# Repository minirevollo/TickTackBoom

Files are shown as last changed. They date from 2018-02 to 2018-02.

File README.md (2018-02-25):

#TICK, TACK ...BOOM

Ein Ratespiel, ähnlich Stadt, Land, Fluss. Hier gibt es die [Spielanleitung](https://github.com/minirevollo/TickTackBoom/blob/master/IMG/TickTackBoom-Spielanleitung.pdf).	

 

Für den Arduino mit nur ein paar Bauteilen.

## Hardware ##
- Arduino (z. B. pro micro)
- OLED-Display 128 x 32 Pixel
- Buzzer passiv
- Button
- LED  (eignebaut)

Anschluß des Displays über I2C an die Pins SDA und SCL (beim Arduino UNO SDA = A4 und SCL = A5 für andere Arduinos bitte den PinOut-Plan beachten).
Der Button kommt auf Pin 7 und GND.
Der Buzzer zwischen Pin 11 und GND. 
Für die LED habe ich die eingbaute auf Pin 13 verwendet.

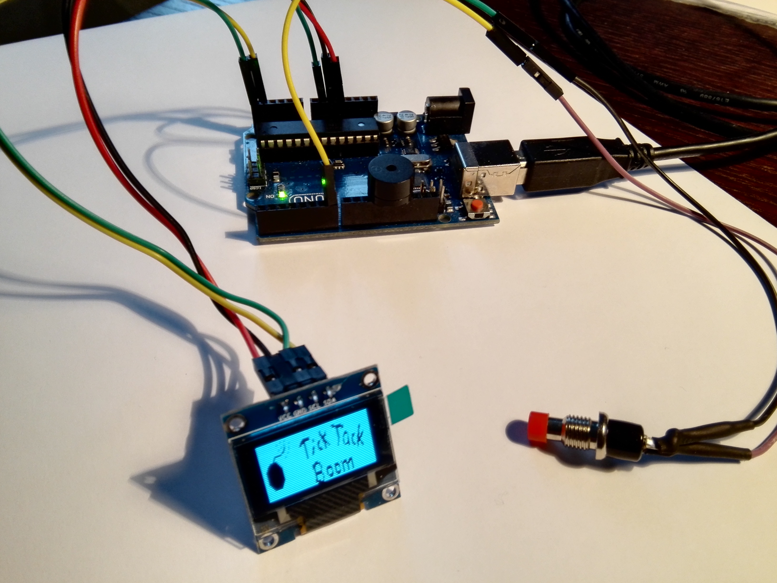
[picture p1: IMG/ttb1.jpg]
     

## Software ##
Arduino-Code über die Arduino-IDE aufspielen.Für absolute Anfänger hier der Link zu [ARDUINO](https://www.arduino.cc/).
Ihr benötigt noch zwei Bibliotheken von [Adafruit](http://www.adafruit.com/):
- Adafruit_GFX.h
- Adafruit_SSD1306.h
- und die entsprechenden .cpp-Dateien

Diese müssen unter dem Ordner 
... C:\Program Files (x86)\Arduino\libraries\Adafruit  abgelegt sein.

Man könnte auch andere OLED-Bibliotheken verwenden. Der Programmcode müsste dann entsprechend angepasst werden. 

Die Daten für den Startbildschirm "Tick Tack Boom" habe ich in meiner Adafruit_SSD1306.cpp Datei hinterlegt. 

Hier liegen normalerweise die Daten für das Adafruit-Logo. Diese Daten habe ich mit meinen Daten ersetzt. Um ein eigenes Logo zu gestalten, erzeuge mit einem Grafikprogramm (z.B. Paint) eine Gif-Datei 128 x 32 Pixel mit euerem gewünschten Motiv. Auf der Website http://www.majer.ch/lcd/adf_bitmap.php kann diese Datei dann in HEX-Daten umgewandelt werden. Die Daten kopieren und die Daten für das Adafruit-Logo damit überschreiben.

Der Code ist so ausgelegt, das für jeden Spielmodus 29 Werte hinterlegt sind. Wenn noch mehr Werte gewünscht sind, müssen die entsprechenden arrays t, b und g entsprechend erweitert werden.

## Gehäuse 

Es wurden zwei Gehäusetypen von mir konstruiert. Zum Einen das komplett 3D-gedruckte Gehäus. Bestehend aus einer Bodenplatte mit Wölbung. Gedacht für zwei zylinderförmige Powerbanks mit einem Durchmesser von ca. 22 mm. Zu befestigen mit zwei dicken Gummibändern. Und dem Oberteil. Innen benötigt man noch eine Stütze für das Display und die Buttonverlängerung. 

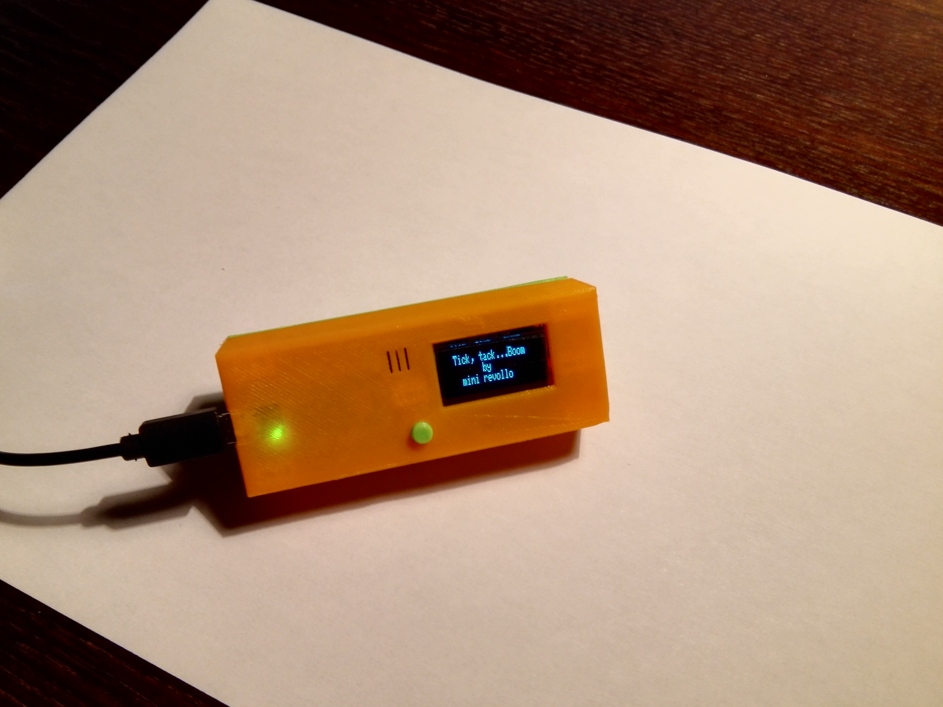
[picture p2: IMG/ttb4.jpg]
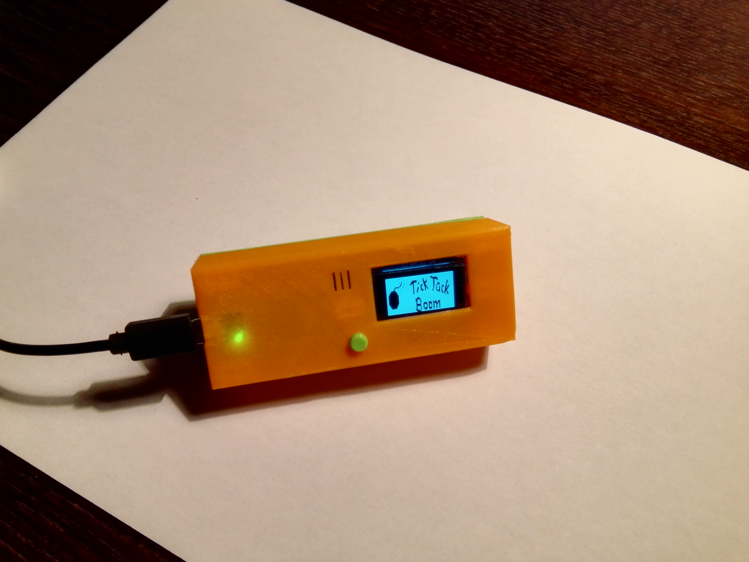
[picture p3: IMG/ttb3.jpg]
     

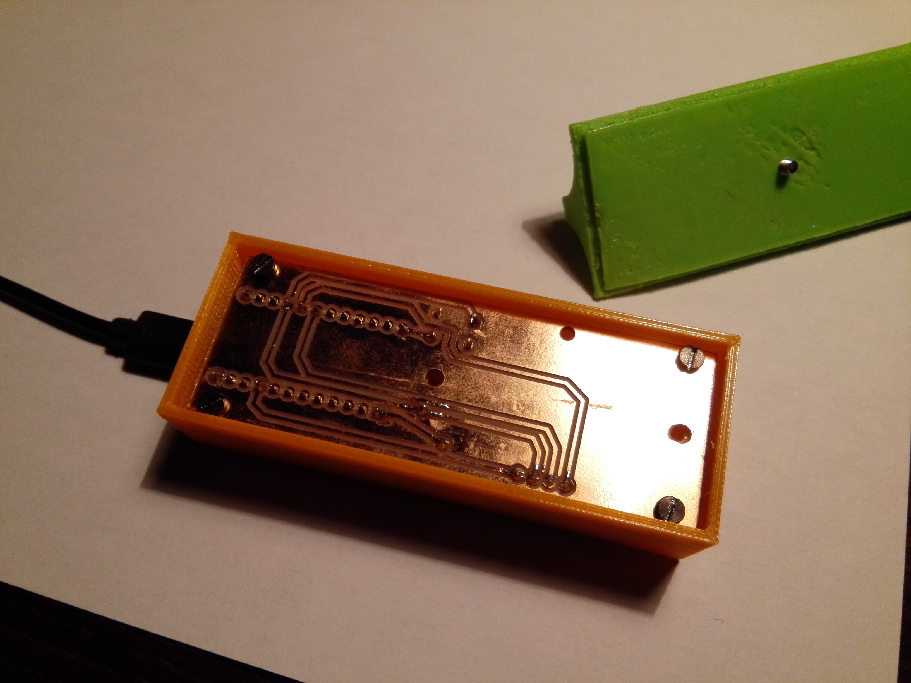
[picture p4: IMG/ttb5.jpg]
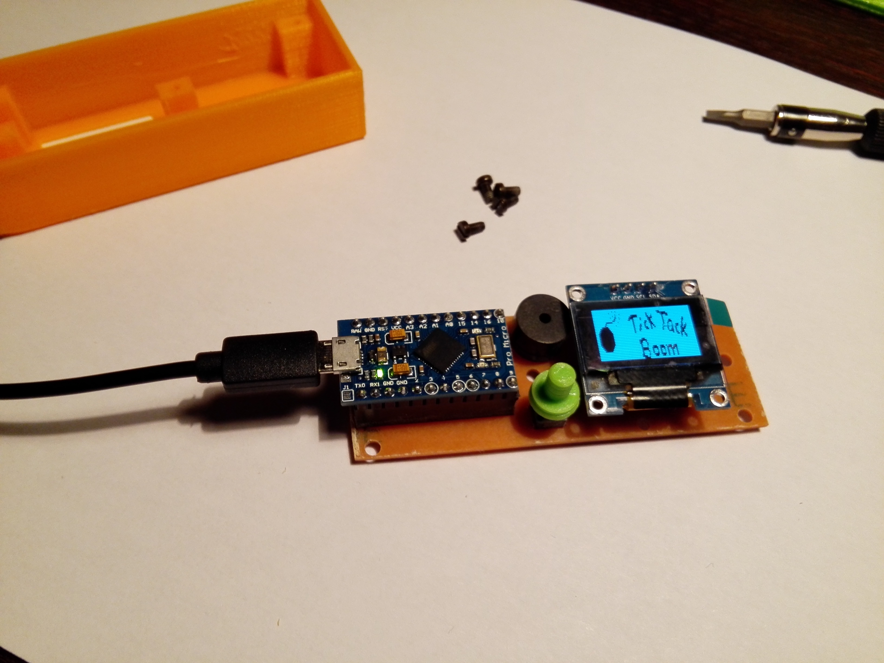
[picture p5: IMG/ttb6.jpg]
  

Für meine Freundin habe ich dann noch die Edelvariante mit Eichenholz und rotem Filament produziert. Der mittlere Teil, die Displaystütze und der Button wurde wieder 3D-gedruckt. Der Deckel und das Unterteil wurde mit einer Othermill gefräst. Hierfür wurde aus der aus Sketchup exportierten DXF-Datei mit [ESTLCAM](http://www.estlcam.de) eine .tap-Datei (g-code) 
erzeugt. 

An dieser Stelle nochmal vielen Dank an Christian, den Programmierer von ESTLCAM, der dem erfindergarden eine Lizenz zur Verfügung gestellt hat.

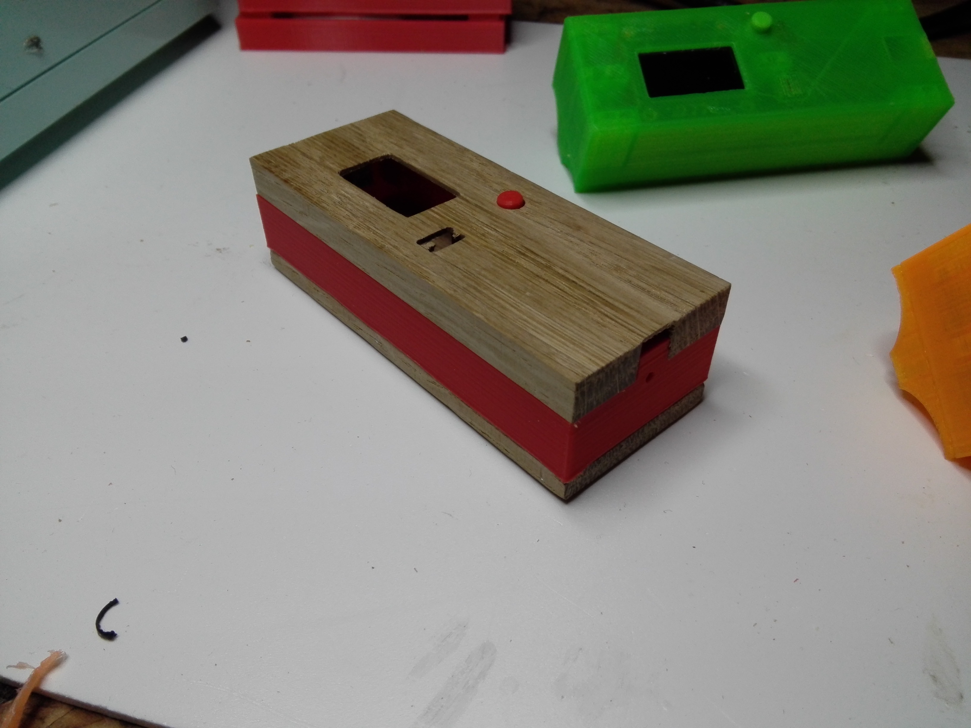
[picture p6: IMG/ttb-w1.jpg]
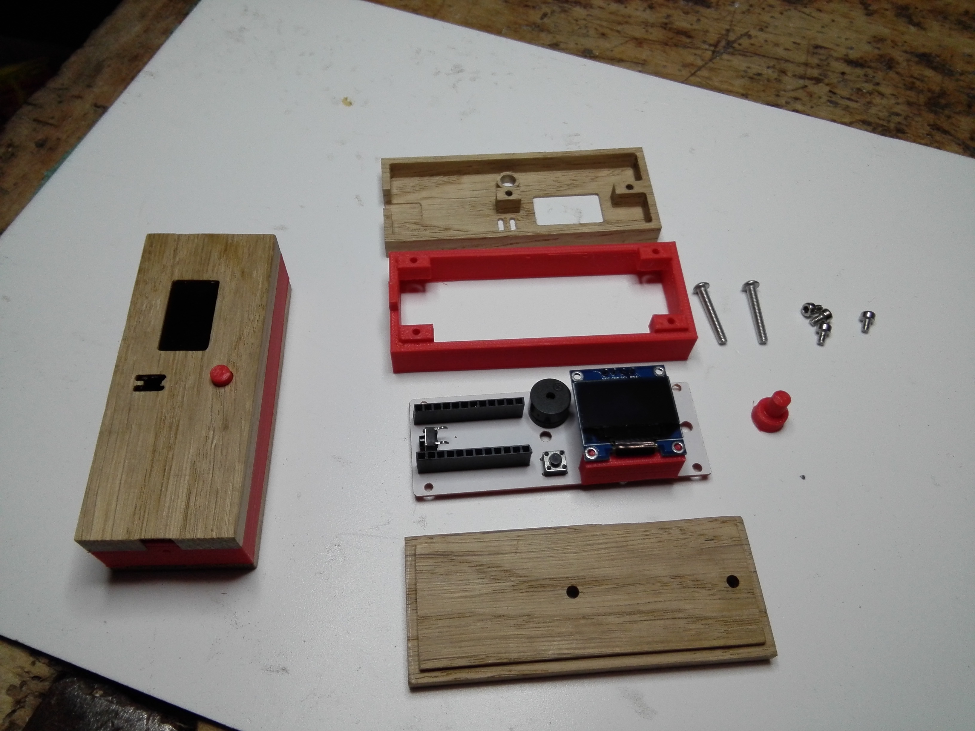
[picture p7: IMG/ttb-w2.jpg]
     

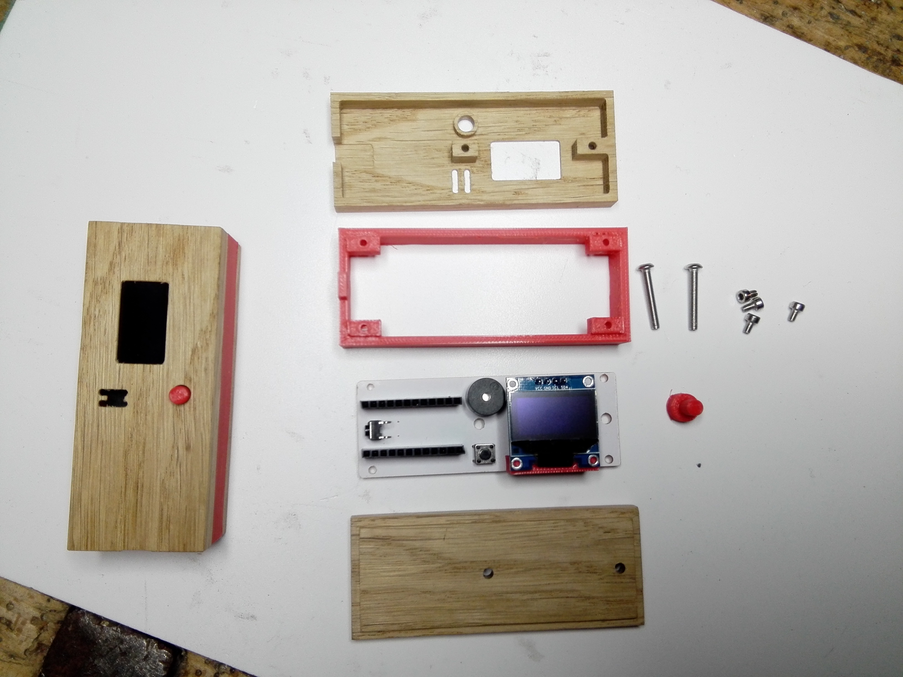
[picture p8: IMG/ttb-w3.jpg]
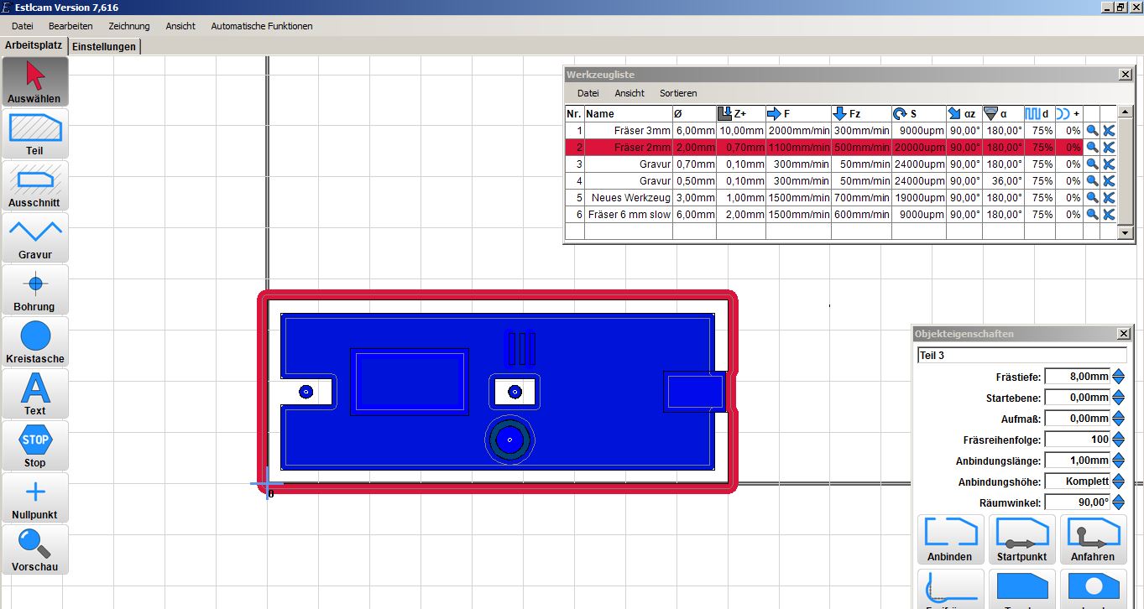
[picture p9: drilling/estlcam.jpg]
 

## Platine: ##

Die Platine wurde mit Fritzing gebaut. Die Form für das Board wurde auch aus der DXF-Datei von Sketchup übernommen und in Inkscape überarbeitet. Um die generierte SVG-Datei für Fritzing nutzbar zu machen muss man einer speziellen Anleitung folgen, die man bei Fritzing auch findet. Export aus Fritzing dann als Gerber-File. Gefräst wieder mit der Othermill.

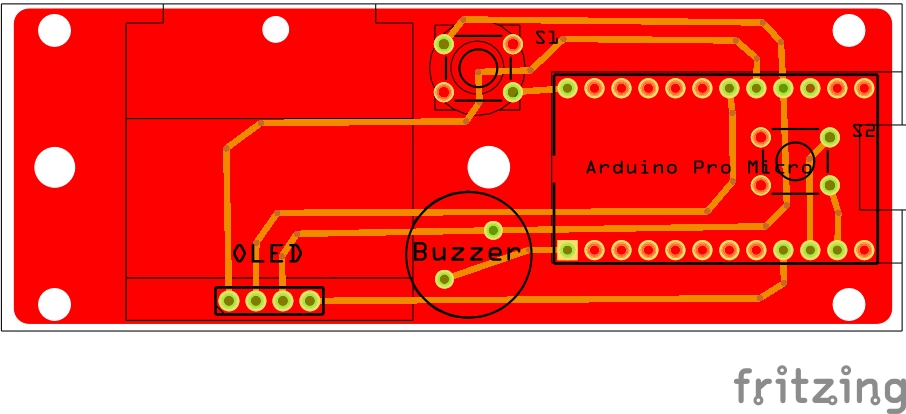
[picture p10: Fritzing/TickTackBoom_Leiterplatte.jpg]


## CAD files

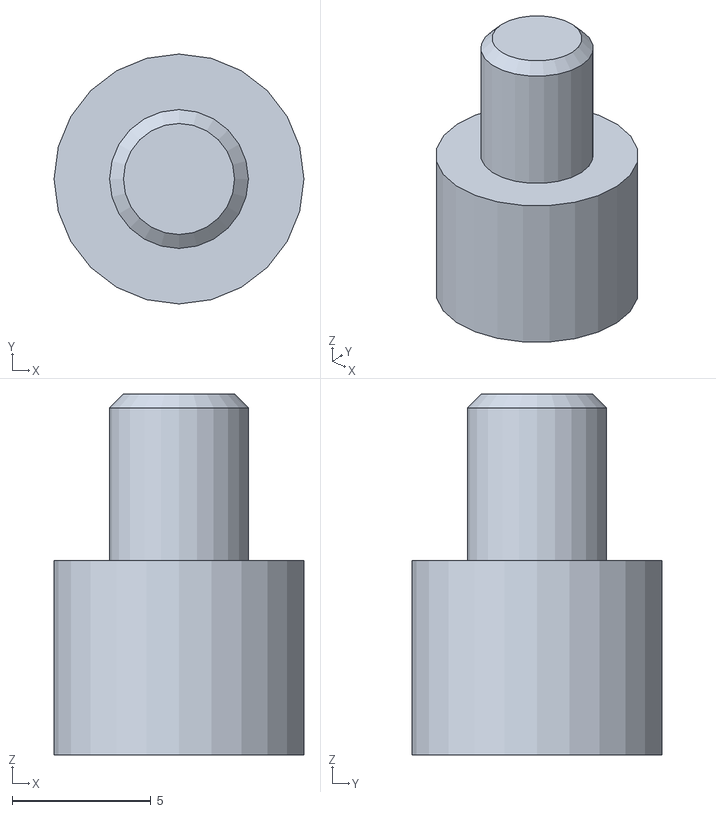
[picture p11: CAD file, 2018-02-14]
3D/ttb_taster_14.stl
9.00 x 9.00 x 13.0

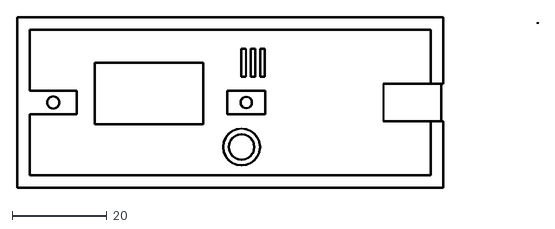
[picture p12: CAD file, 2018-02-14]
drilling/TickTackBoom_Holz.dxf
110.4 x 36.4

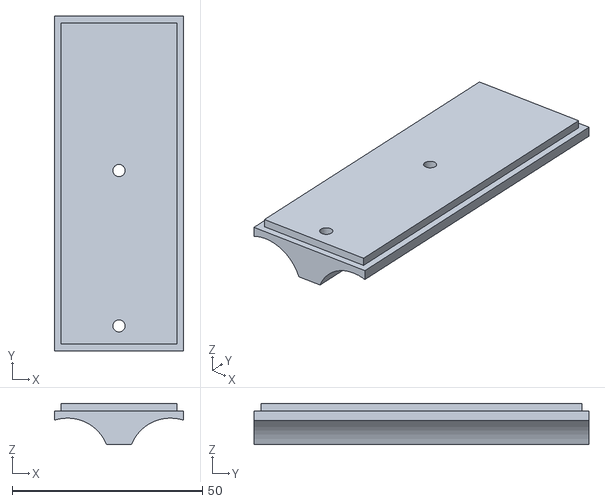
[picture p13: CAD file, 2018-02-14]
3D/ttb_unterteil.stl
34.0 x 88.0 x 10.9

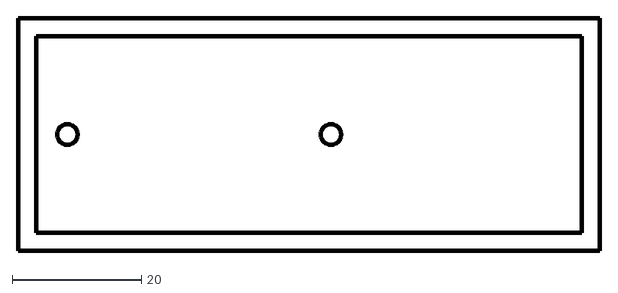
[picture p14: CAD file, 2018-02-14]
drilling/TickTackBoom_Holz_unten.dxf
90.6 x 36.6

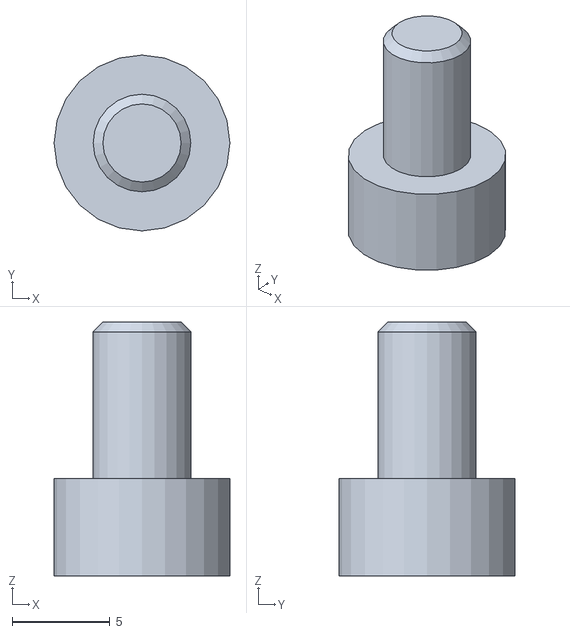
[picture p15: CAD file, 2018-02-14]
3D/ttb_taster_13.stl
9.00 x 9.00 x 13.0

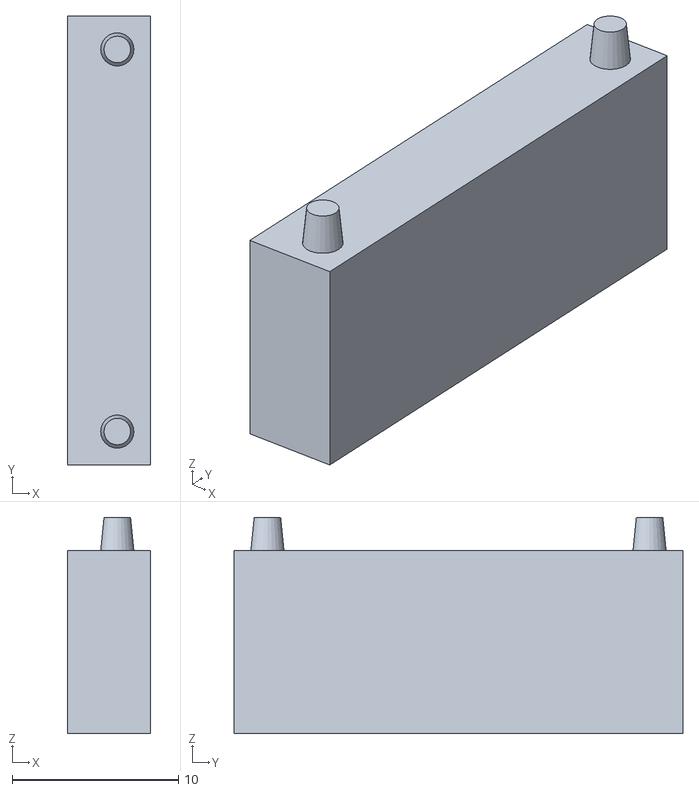
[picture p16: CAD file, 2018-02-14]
3D/ttb_stuetze.stl
5.00 x 27.0 x 13.0

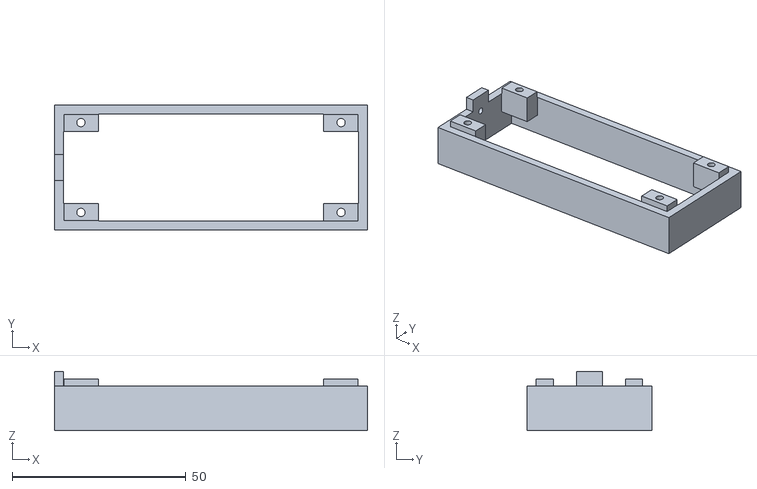
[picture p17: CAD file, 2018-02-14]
3D/ttb_holz_oberteil.stl
90.0 x 36.0 x 17.0

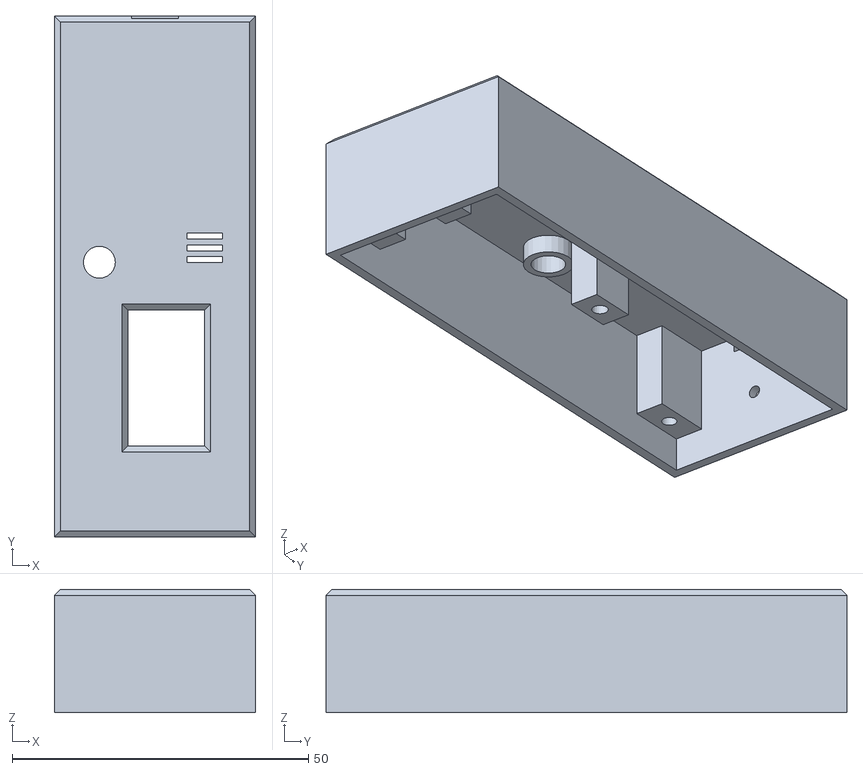
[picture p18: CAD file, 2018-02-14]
3D/ttb_oberteil.stl
34.0 x 88.0 x 20.8

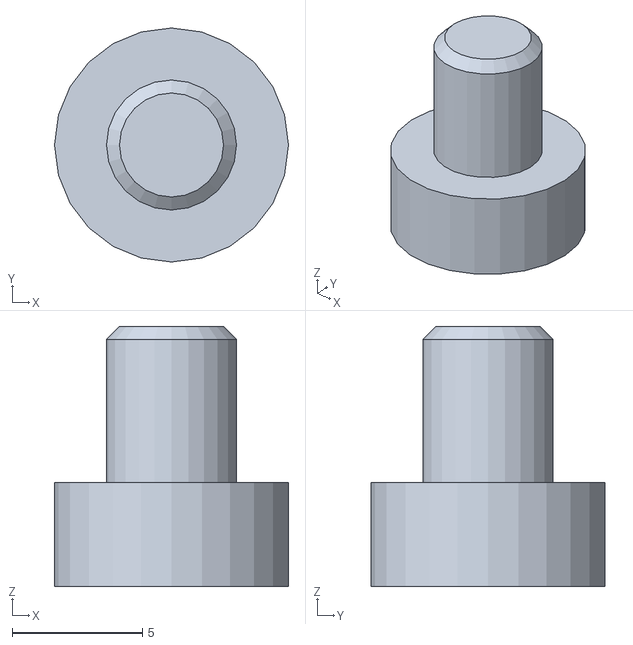
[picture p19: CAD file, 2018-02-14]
3D/ttb_taster_10.stl
9.00 x 9.00 x 10.00

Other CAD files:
3D/TickTackBoom.skp
3D/TickTackBoom_Holz.skp

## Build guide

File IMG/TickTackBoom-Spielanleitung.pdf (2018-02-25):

### Tick Tack Boom

Spielanleitung

Für große und kleine Kinder.

… die Bombe tickt … es bleibt nur kurze Zeit die Aufgabe zu lösen und die Verantwortung weiter zu reichen. Bei einer Teillösung kommt die Bombe nach einer Runde wieder zu Dir. Nur wenn die Aufgabe komplett erledigt ist kannst Du die Bombe einfach weiter reichen.

Aus vier Spielmodi wird per Zufall eine Aufgabe gestellt:

- Das Thema: Nenne einen Begriff passend zum Thema mit dem gezeigtem Anfangsbuchstaben und reiche die Bombe weiter
- Der Bekannte: Nenne eine bekannte Person mit den angezeigten Initialen. Es genügt fürs Erste, dass der Vorname oder der Nachname übereinstimmt. Es muss aber Vor- und Nachname genannt werden. Um aber komplett aus dem Schneider zu sein, müssen Vor- und Nachname passen.
- Vermischt: Welches Wort versteckt sich hinter der Buchstabenmischung? Um die Bombe
weiter reichen zu können, | genügt es aus

den vorhandenen Buchstaben ein kleines Wort zu bilden. Um die nächsten Runden zu überspringen muss das komplett richtige Wort erraten werden.
- Worteil: Nenne ein zusammengefügtes Wort unter den angegebenen Bedingungen

Ein Spiel aus dem www.erfindergarden.de , das Fablab in der Au – München, Designe by Mini Revollo … Feb. 2018

99 % of art is copy

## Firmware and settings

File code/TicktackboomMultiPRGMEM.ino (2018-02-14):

/*Tick Tack Boom umgestaltet von Mini Revollo, 
 * Januar 2018 im erfindergarden
 * Eine Art "Stadt, Land, Fluss" mit einer tickenden Bombe, 
 * die jederzeit hochgehen kann
 * Anzeige auf einem OLED und  Blinklicht, Sound über Buzzer oder Lautsprecher
 */
#include <Wire.h>  // Uno: scl->A5 SDA ->A4  Leonardeo:
#include <Adafruit_GFX.h>
#include <Adafruit_SSD1306.h>
#define OLED_RESET 4
Adafruit_SSD1306 display(OLED_RESET);
#define NUMFLAKES 10
#define XPOS 0
#define YPOS 1
#define DELTAY 2
#define LOGO16_GLCD_HEIGHT 32 
#define LOGO16_GLCD_WIDTH  128

const char t0[] PROGMEM = "Badespass";
const char t1[] PROGMEM = "Elektrogeraet";
const char t2[] PROGMEM = "Waffe";
const char t3[] PROGMEM = "Weltall";
const char t4[] PROGMEM = "Fahrzeug";
const char t5[] PROGMEM = "Behaelter";
const char t6[] PROGMEM = "Raeume";
const char t7[] PROGMEM = "Tatmotive";
const char t8[] PROGMEM = "Getraenke";
const char t9[] PROGMEM = "Tatort";
const char t10[] PROGMEM = "Fluchtfahrzeuge";
const char t11[] PROGMEM = "Sportgeraet";
const char t12[] PROGMEM = "Tanzstil";
const char t13[] PROGMEM = "Koerperteil";
const char t14[] PROGMEM = "Krankheit";
const char t15[] PROGMEM = "Kompliment";
const char t16[] PROGMEM = "X";
const char t17[] PROGMEM = "X";
const char t18[] PROGMEM = "X";
const char t19[] PROGMEM = "X";
const char t20[] PROGMEM = "X";
const char t21[] PROGMEM = "X";
const char t22[] PROGMEM = "X";
const char t23[] PROGMEM = "X";
const char t24[] PROGMEM = "X";
const char t25[] PROGMEM = "X";
const char t26[] PROGMEM = "X";
const char t27[] PROGMEM = "X";
const char t28[] PROGMEM = "X";
const char t29[] PROGMEM = "X";
const char t30[] PROGMEM = "X";  //letzter Eintrag immer ein X
const char* const t[] PROGMEM = {t0, t1, t2, t3, t4, t5, t6, t7, t8, t9, t10, t11, t12,
                                t13, t14, t15, t16, t17, t18, t19, t20, t21, t22, t23,
                                t24, t25, t26, t27, t28, t29, t30};
const char b0[] PROGMEM = "LT";
const char b1[] PROGMEM = "PP";
const char b2[] PROGMEM = "GU";
const char b3[] PROGMEM = "LM";
const char b4[] PROGMEM = "SM";
const char b5[] PROGMEM = "WI";
const char b6[] PROGMEM = "BB";
const char b7[] PROGMEM = "CB";
const char b8[] PROGMEM = "OW";
const char b9[] PROGMEM = "TH";
const char b10[] PROGMEM = "FE";
const char b11[] PROGMEM = "AR";
const char b12[] PROGMEM = "HE";
const char b13[] PROGMEM = "MA";
const char b14[] PROGMEM = "KM";
const char b15[] PROGMEM = "DH";
const char b16[] PROGMEM = "PP";
const char b17[] PROGMEM = "GU";
const char b18[] PROGMEM = "LM";
const char b19[] PROGMEM = "SM";
const char b20[] PROGMEM = "WI";
const char b21[] PROGMEM = "BB";
const char b22[] PROGMEM = "CB";
const char b23[] PROGMEM = "OW";
const char b24[] PROGMEM = "TH";
const char b25[] PROGMEM = "FE";
const char b26[] PROGMEM = "AR";
const char b27[] PROGMEM = "HE";
const char b28[] PROGMEM = "MA";
const char b29[] PROGMEM = "KM";
const char b30[] PROGMEM = "X";  //letzter Eintrag immer ein X
const char* const b[] PROGMEM = {b0, b1, b2, b3, b4, b5, b6, b7, b8, b9, b10, b11, b12, b13, 
                                  b14, b15, b16, b17, b18, b19, b20, b21, b22, b23, b24, 
                                  b25, b26, b27, b28, b29, b30};
const char g0[] PROGMEM = "H L A L E B A N D";  //Hallenbad
const char g1[] PROGMEM = "T O R N A I N T O";  //Notration
const char g2[] PROGMEM = "D E C E T K T E B";   //
const char g3[] PROGMEM = "B F I E R E I";  //Freibier
const char g4[] PROGMEM = "A B L A L D N H";  //Handball
const char g5[] PROGMEM = "P E E C H A P K K L";
const char g6[] PROGMEM = "W A H C T H S I C S";  //Waschtisch
const char g7[] PROGMEM = "E T R H E N T I U R";
const char g8[] PROGMEM = "I A L S B H N E";  //Seilbahn
const char g9[] PROGMEM = "F O S A T P N";
const char g10[] PROGMEM = "U U F R C B H A";  //Aufbruch
const char g11[] PROGMEM = "S E U R M N A P";  //Superman
const char g12[] PROGMEM = "S R A E E T G U I";  //Sauerteig
const char g13[] PROGMEM = "H E R L N T D A N I";//Hinterland
const char g14[] PROGMEM = "E W U K H E I D";//Kuhweide
const char g15[] PROGMEM = "K P N A E F R";//Krapfen
const char g16[] PROGMEM = "X";
const char g17[] PROGMEM = "X";
const char g18[] PROGMEM = "X";
const char g19[] PROGMEM = "X";
const char g20[] PROGMEM = "X";
const char g21[] PROGMEM = "X";
const char g22[] PROGMEM = "X";
const char g23[] PROGMEM = "X";
const char g24[] PROGMEM = "X";
const char g25[] PROGMEM = "X";
const char g26[] PROGMEM = "X";
const char g27[] PROGMEM = "X";
const char g28[] PROGMEM = "X";
const char g29[] PROGMEM = "X";
const char g30[] PROGMEM = "X";  //letzter Eintrag immer ein X
const char* const g[] PROGMEM = {g0, g1, g2, g3, g4, g5, g6, g7, g8, g9, g10, g11,
                                g12, g13, g14, g15, g16, g17, g18, g19, g20, 
                                g21,g22, g23, g24, g25,g26,g27,g28,g29,g30};

const char p0[] PROGMEM = "darf nicht vorne";
const char p1[] PROGMEM = "darf nicht hinten";
const char p2[] PROGMEM = "darf nicht mittig";
const char p3[] PROGMEM = "muss vorne";
const char p4[] PROGMEM = "muss hinten";
const char p5[] PROGMEM = "muss mittig";
const char p6[] PROGMEM = "X";  //letzter Eintrag immer ein X
const char* const p[] PROGMEM = {p0, p1, p2, p3, p4, p5, p6}; 

const char w0[] PROGMEM = "Post";
const char w1[] PROGMEM = "Post";
const char w2[] PROGMEM = "Auto";
const char w3[] PROGMEM = "Hof";
const char w4[] PROGMEM = "Bier";
const char w5[] PROGMEM = "Heim";
const char w6[] PROGMEM = "Frei";
const char w7[] PROGMEM = "Zeit";
const char w8[] PROGMEM = "Post";
const char w9[] PROGMEM = "Auto";
const char w10[] PROGMEM = "Hof";
const char w11[] PROGMEM = "Bier";
const char w12[] PROGMEM = "Heim";
const char w13[] PROGMEM = "Frei";
const char w14[] PROGMEM = "X";  //letzter Eintrag immer ein X
const char* const w[] PROGMEM = {w0, w1, w2, w3, w4, w5, w6, w7, w8, w9, w10, w11, w12, w13, w14};                                

int laenge_thema = 0;   //Länge der array thema
int laenge_bekannt = 0;   //Länge der array bekannt
int laenge_gemischt = 0;   //Länge der array gemischt
int laenge_position = 0;     //Länge der array position
int laenge_wort = 0;    //Länge der array wort
#define button_Pin  9  //Startbutton
#define LED 17           //Blinklicht rot   bei Leonardo die Pin 17 ist RX-LED
//#define LED 13           //Blinklicht rot   eingebaute LED bei UNO
#define BUZZER 10         //Buzzer passiv
int button_state = 0;   //Status button
int menue = 0;          //menue 0, 1 = Anzeige Tehma, 2 = Bombe tickt  
long ratezeit = 120000;   //maximale Ratezeit, min 3000, 1000 = 1 sek
long dauer = 0;          //Zeit zum Raten die per Zufall ausgewählt wird
long startzeit = 0;       //Startzeit
int buchstabe = 0;      //ASCII Code für a - z
int thema_nr = 0;       //Auswahl des Themas
int bekannt_nr = 0;        //Auswahl des bekannt
int gemischt_nr = 0;        //Auswahl des gemischt
int position_nr = 0;        //Auswahl des Ortes
int wort_nr = 0;                //Auswahl des Wortes
int modus = 0;           //modus = Thema, Initialien oder Buchstabenmischung
char buffer[30];    //puffer um dem PROGMEM auszulesen

void setup() {
  // by default, we'll generate the high voltage from the 3.3v line internally! (neat!)
  display.begin(SSD1306_SWITCHCAPVCC, 0x3C);  // initialize with the I2C addr 0x3C (for the 128x32)
  // init done
  // Show image buffer on the display hardware.
  // Since the buffer is intialized with an Adafruit splashscreen
  // internally, this will display the splashscreen.
  display.display();
  delay(5000);
  
  pinMode(button_Pin, INPUT);
  digitalWrite(button_Pin, HIGH);   //internal Pullup
  pinMode(LED, OUTPUT);
  pinMode(BUZZER, OUTPUT);
 /*
  Serial.begin(9600);
  while(!Serial){
    ;
    }
*/
  while(buffer[0] != 'X'){           //zählt die Themen durch
      strcpy_P(buffer, (char*)pgm_read_word(&(t[laenge_thema]))); 
      laenge_thema ++;
      Serial.println(buffer);
      Serial.println(laenge_thema);
      }
  laenge_thema = laenge_thema - 2; 
  buffer[0] = 'Z';
  while(buffer[0] != 'X'){           //zählt die bekannt durch
      strcpy_P(buffer, (char*)pgm_read_word(&(b[laenge_bekannt]))); 
      laenge_bekannt ++;
      Serial.println(buffer);
      Serial.println(laenge_bekannt);
      } 
   laenge_bekannt = laenge_bekannt - 2; 
   buffer[0] = 'Z'; 
   
   while(buffer[0] != 'X'){           //zählt die gemischt durch
      strcpy_P(buffer, (char*)pgm_read_word(&(g[laenge_gemischt]))); 
      laenge_gemischt ++;
      Serial.println(buffer);
      Serial.println(laenge_gemischt);
      }     
   laenge_gemischt = laenge_gemischt - 2;
   buffer[0] = 'Z';
   
   while(buffer[0] != 'X'){           //zählt die Positionen durch
      strcpy_P(buffer, (char*)pgm_read_word(&(p[laenge_position]))); 
      laenge_position ++;
      Serial.println(buffer);
      Serial.println(laenge_position);
      }     
   laenge_position = laenge_position - 2;
   buffer[0] = 'Z';
   
   while(buffer[0] != 'X'){           //zählt die Worte durch
      strcpy_P(buffer, (char*)pgm_read_word(&(w[laenge_wort]))); 
      laenge_wort ++;
      Serial.println(buffer);
      Serial.println(laenge_wort);
      }     
   laenge_wort = laenge_wort - 2;
   
  display.clearDisplay();         //clear the screen 
  display.setCursor(10, 0);        // Set cursor to top-left
  display.setTextColor(WHITE);
  display.setTextSize(1);         // font size
  display.println(F("Tick, tack...Boom")); //Print the String
  display.setCursor(50, 8);        // Set cursor
  display.println(F("by")); //Print the String
  display.setCursor(20, 16);        // Set cursor 
  display.print(F("mini revollo")); 
  display.display();
  delay(5000);
  display.setCursor(0,24);        // Set cursor to top-left
  display.setTextSize(1);         // font
  display.print(F("Drueck den Button!")); 
  display.display();
 
}

void loop() {
    
  while(menue == 0){    
    modus = random(0,3);   //wählt den spielmodus aus
    buttonabfrage();
   }

  switch (modus) {
  case 0: //thema
    thema_nr = random(0,laenge_thema);
    dauer = random(2000,ratezeit);
    buchstabe = random(65, 82);
    display.clearDisplay();
    display.setCursor(20, 4);
    strcpy_P(buffer, (char*)pgm_read_word(&(t[thema_nr]))); 
    display.println(buffer);
    display.setCursor(0, 22);
    display.println(F("mit:")); 
    display.setCursor(50,18);        // Set cursor
    display.setTextSize(2);
    display.write(buchstabe);
    display.setTextSize(1); 
    display.display();
    
    startzeit = millis();
    menue = 2;
    break;
    
  case 1: //bekannt
    bekannt_nr = random(0,laenge_bekannt);
    display.clearDisplay();           //clear the screen 
    display.setCursor(0, 0);
    display.println(F("Bekannter mit den")); //Print the String
    display.print(F("Initialen:")); //Print the String
    display.setCursor(73, 16);
    display.setTextSize(2);
    strcpy_P(buffer, (char*)pgm_read_word(&(b[bekannt_nr]))); 
    display.println(buffer);
    display.setTextSize(1); 
    display.display();
    
    dauer = random(2000,ratezeit);
    startzeit = millis();
    menue = 2;
    break;
    
  case 2: //Wort auf Postion
    wort_nr = random(0,laenge_wort);
    position_nr = random(0, laenge_position);
    display.clearDisplay();           //clear the screen 
    display.setCursor(0, 0);
    display.print(F("Das Wort  ")); //Print the String
    //display.setCursor(20, 12);
    display.setTextSize(2);
    strcpy_P(buffer, (char*)pgm_read_word(&(w[wort_nr]))); 
    display.println(buffer);
    display.setTextSize(1);
    strcpy_P(buffer, (char*)pgm_read_word(&(p[position_nr]))); 
    display.println(buffer);
    display.println(F("stehen")); //Print the String   
    display.display();
    
    dauer = random(2000,ratezeit);
    startzeit = millis();
    menue = 2;
    break; 
     
  default:  //gemischt
    gemischt_nr = random(0,laenge_gemischt);
    display.clearDisplay();           //clear the screen 
    display.setCursor(0, 0);
    display.println(F("   gemischtes Wort")); //Print the String
    display.setCursor(0,20 );
    strcpy_P(buffer, (char*)pgm_read_word(&(g[gemischt_nr]))); 
    display.println(buffer);
    display.display();
    
    dauer = random(2000,ratezeit);
    startzeit = millis();
    menue = 2;
}
  
  while(menue == 2){
    countdown();  
  }
}

//------------------------ buttonabfrage ---------------------------------

void buttonabfrage(){
   if(digitalRead(button_Pin)== LOW && button_state == 0){
        button_state = 1; 
   }
   if(digitalRead(button_Pin) == HIGH && button_state == 1){
        button_state = 0;
        menue = menue + 1;
        if(menue > 2){
            menue = 0;
        }
   }
   delay(100);   //debounce
}
//----------------------- buttonabfrage ende --------------------------------
//----------------------- countdown -----------------------------------------
void countdown(){
    digitalWrite(LED, LOW);   //RS LED kann kassisch geschaltet werden nur gedreht
//    TXLED0;   //// Makro um die eingebaute TX-LED einzuschalten
    tone(BUZZER,300,100); 
    delay(500);
    digitalWrite(LED, HIGH);  //RS LED kann kassisch geschaltet werden nur gedreht
//    TXLED1;  // Makro um die eingebaute TX-LED auszuschalten
    tone(BUZZER,150,100); 
    delay(500);
    if(millis()>= startzeit + dauer){
      for(int i=0; i<=20; i++){
        tone(BUZZER,150);
        delay(10);
        tone(BUZZER,170);
        delay(10);
        tone(BUZZER,50);
        delay(10);
        tone(BUZZER,600);
        delay(10);
        tone(BUZZER,100);
        delay(10);
        tone(BUZZER,60); 
        delay(10);       
        }
      noTone(BUZZER);
      
      menue = 0;
    }
}
//------------------------- countdown ende ----------------------------------
